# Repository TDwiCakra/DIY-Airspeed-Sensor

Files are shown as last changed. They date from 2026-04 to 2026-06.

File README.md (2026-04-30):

# Airspeed Sensor - Sistem Pengukur Kecepatan Udara





Sistem pengukur kecepatan udara berbasis prinsip Pitot Tube menggunakan dua sensor barometer BMP280, dilengkapi dengan Kalman Filter untuk pembacaan yang stabil dan akurat.

Note:
- Pastikan kedua sensor BMP280 terpasang dengan benar sebelum upload program
- Lakukan kalibrasi awal (zeroing) dengan menekan tombol saat kondisi angin tenang / tidak ada aliran udara

## 💡 Cara Kerja

Sistem ini mengukur kecepatan udara menggunakan prinsip **Pitot Tube** yang memanfaatkan perbedaan tekanan statis dan tekanan dinamis:

```
                    ┌──────────────┐
   Aliran Udara →   │   BMP280 #1  │  (Stagnation / Dynamic Pressure)
                    └──────────────┘
                          vs
                    ┌──────────────┐
   Aliran Udara →   │   BMP280 #2  │  (Static Pressure)
                    └──────────────┘
                           ↓
              Hitung ΔP = P1 - P2 - Offset
                           ↓
              v = √(2 × |ΔP| / ρ) × 3.6  [km/h]
                           ↓
              Output difilter dengan Kalman Filter
```

Kecepatan dihitung menggunakan persamaan Bernoulli, lalu diperhalus dengan **Kalman Filter** untuk meredam noise sensor.

---

## 🌟 Fitur Utama

- ✅ Pengukuran kecepatan udara real-time (km/h)
- ✅ Dual BMP280 sensor (I2C address 0x76 & 0x77)
- ✅ Kalman Filter untuk output yang stabil dan minim noise
- ✅ Kalibrasi otomatis offset tekanan saat startup (20 sampel)
- ✅ Fungsi Zeroing / Re-kalibrasi via tombol tekan
- ✅ Deadzone threshold (< 0.5 Pa = 0 km/h) untuk menghindari noise saat diam
- ✅ Offset koreksi suhu per sensor
- ✅ Output Serial Monitor lengkap (Suhu, Raw Speed, Filtered Speed)

---

## 🛠 Hardware Requirements

| Komponen | Spesifikasi | Jumlah |
|---|---|---|
| **Microcontroller** | Arduino (Uno/Nano/Mega) | 1 |
| **Pressure Sensor** | BMP280 (I2C, address 0x76) | 1 |
| **Pressure Sensor** | BMP280 (I2C, address 0x77) | 1 |
| **Push Button** | Tactile Switch / Push Button | 1 |
| **Resistor** | 10kΩ (opsional, sudah ada internal pullup) | 1 |
| **Pitot Tube** | Tabung pitot untuk mengarahkan angin | 1 |
| **Breadboard/PCB** | Untuk koneksi | 1 |
| **Kabel Jumper** | Male-Female, Male-Male | Secukupnya |

---

## 📥 Instalasi Arduino IDE

### Windows

1. **Download Arduino IDE**
   - Kunjungi [Arduino Official Website](https://www.arduino.cc/en/software)
   - Download versi terbaru (2.x.x atau 1.8.x)
   - Pilih "Windows Installer" (untuk instalasi mudah)

2. **Install Arduino IDE**
   - Jalankan file installer (.exe)
   - Ikuti wizard instalasi
   - Centang "Install USB Driver" saat instalasi
   - Klik "Finish" setelah selesai

3. **Buka Arduino IDE**
   - Jalankan Arduino IDE dari Start Menu
   - IDE siap digunakan

### macOS

1. **Download Arduino IDE**
   - Kunjungi [Arduino Official Website](https://www.arduino.cc/en/software)
   - Download versi untuk macOS

2. **Install Arduino IDE**
   - Buka file .dmg yang didownload
   - Drag aplikasi Arduino ke folder Applications
   - Buka Arduino IDE dari Applications

### Linux (Ubuntu/Debian)

```bash
# Download dan install Arduino IDE
wget https://downloads.arduino.cc/arduino-ide/arduino-ide_latest_Linux_64bit.AppImage

# Berikan permission untuk execute
chmod +x arduino-ide_latest_Linux_64bit.AppImage

# Jalankan Arduino IDE
./arduino-ide_latest_Linux_64bit.AppImage
```

Atau install via snap:

```bash
sudo snap install arduino
```

---

## 📚 Instalasi Library

Program ini hanya menggunakan library bawaan Arduino sehingga **tidak memerlukan instalasi library tambahan**!

Library yang digunakan:

| Library | Keterangan | Status |
|---|---|---|
| `Wire.h` | Komunikasi I2C | ✅ Built-in Arduino |

### Verifikasi Library Terinstall

```cpp
// Buka Arduino IDE dan coba compile sketch ini:
#include <Wire.h>

void setup() {}
void loop() {}
```

Jika tidak ada error, library sudah siap digunakan!

---

## 🔧 Konfigurasi Hardware

### Wiring Diagram

#### I2C Connection (BMP280 #1 & BMP280 #2)

```
Arduino UNO      BMP280 #1 (0x76)
--------------------------
5V / 3.3V  -----> VCC
GND        -----> GND
A4 (SDA)   -----> SDA
A5 (SCL)   -----> SCL
SDO        -----> GND   ← untuk set alamat 0x76

Arduino UNO      BMP280 #2 (0x77)
--------------------------
5V / 3.3V  -----> VCC
GND        -----> GND
A4 (SDA)   -----> SDA  (parallel dengan BMP280 #1)
A5 (SCL)   -----> SCL  (parallel dengan BMP280 #1)
SDO        -----> VCC  ← untuk set alamat 0x77
```

**⚠️ Penting:** Pin `SDO` pada BMP280 digunakan untuk mengatur alamat I2C:
- `SDO → GND` = alamat **0x76**
- `SDO → VCC` = alamat **0x77**

#### Tombol Zeroing

```
Arduino UNO      Button
--------------------------
D2         -----> PIN 1
GND        -----> PIN 2
```

> Internal Pull-Up diaktifkan via `INPUT_PULLUP`, sehingga tidak diperlukan resistor eksternal.

### Tips Pemasangan

1. **Sensor BMP280 #1 (Dynamic / Stagnation)**
   - Pasang menghadap aliran udara (sisi lubang pitot tube)
   - Pastikan lubang inlet tidak tertutup

2. **Sensor BMP280 #2 (Static Pressure)**
   - Pasang pada sisi yang tidak terkena aliran langsung
   - Jauhkan dari turbulensi yang tidak diinginkan

3. **Tombol Zeroing**
   - Tempatkan di posisi yang mudah dijangkau
   - Tekan saat sistem tidak ada aliran udara untuk kalibrasi ulang

---

## 📤 Upload Program ke Arduino

### 1. Persiapan

1. **Buka File Program**
   - Download file `Airspeed_Sensor.ino`
   - Buka dengan Arduino IDE: `File → Open`

2. **Sesuaikan Offset Suhu (Opsional)**

   Edit bagian ini di dalam `void loop()` jika sensor menunjukkan suhu yang tidak akurat:
   ```cpp
   float t1 = readTemperature(0x76, cal1, -1.5);   // Offset sensor #1 (-1.5°C)
   readTemperature(0x77, cal2, -8.89);              // Offset sensor #2 (-8.89°C)
   ```
   Sesuaikan nilai offset dengan mengukur selisih suhu aktual terhadap referensi termometer.

### 2. Konfigurasi Board

1. **Pilih Board**
   - `Tools → Board → Arduino AVR Boards → Arduino Uno` (sesuaikan dengan board Anda)

2. **Pilih Port COM**
   - Hubungkan Arduino ke komputer via USB
   - `Tools → Port → COMx` (Windows) atau `/dev/ttyUSBx` (Linux) atau `/dev/cu.usbmodem-xxx` (macOS)

3. **Konfigurasi Upload Settings (Arduino Uno)**
   ```
   Tools → Board: Arduino Uno
   Tools → Processor: ATmega328P
   Tools → Upload Speed: 115200
   ```

### 3. Compile & Upload

1. **Verify/Compile**
   - Klik tombol ✓ (Verify) atau `Sketch → Verify/Compile`
   - Tunggu hingga proses compile selesai
   - Pastikan tidak ada error

2. **Upload ke Arduino**
   - Klik tombol → (Upload) atau `Sketch → Upload`
   - Tunggu proses upload selesai

3. **Buka Serial Monitor**
   - `Tools → Serial Monitor`
   - Set baud rate ke **9600**
   - Tunggu pesan `"System Ready. Press Button to Toggle ON/OFF."`

---

## 🚀 Penggunaan

### Startup & Kalibrasi Awal

Saat pertama dinyalakan, sistem akan otomatis melakukan kalibrasi:

```
Calibrating... Please wait.
System Ready. Press Button to Toggle ON/OFF.
```

Kalibrasi dilakukan dengan mengambil **20 sampel** selisih tekanan antara kedua sensor dan menghitung rata-rata sebagai `pressure_offset`. Proses ini memakan waktu sekitar **1 detik**.

> ⚠️ **Pastikan tidak ada aliran udara saat proses kalibrasi startup berlangsung!**

### Membaca Output Serial

Setelah sistem ready, output akan tampil setiap 50ms:

```
Temp:25.30 Raw_V:12.45 Filtered_V:11.87
Temp:25.31 Raw_V:12.60 Filtered_V:12.10
Temp:25.30 Raw_V:0.00  Filtered_V:8.32
```

| Field | Keterangan | Satuan |
|---|---|---|
| `Temp` | Suhu dari BMP280 #1 (sudah terkoreksi offset) | °C |
| `Raw_V` | Kecepatan mentah sebelum filtering | km/h |
| `Filtered_V` | Kecepatan setelah Kalman Filter | km/h |

### Zeroing / Re-kalibrasi

Tekan tombol di **Pin D2** kapan saja untuk melakukan re-kalibrasi:

```
Zeroing / Recalibrating...
New Offset: 0.35
```

Sistem akan mengambil **10 sampel** baru dan memperbarui `pressure_offset`. Estimasi Kalman Filter juga di-reset ke 0 untuk menghindari lonjakan nilai.

---

## 🔬 Penjelasan Algoritma

### 1. Pembacaan BMP280 via I2C (Raw Driver)

Program ini **tidak menggunakan library BMP280 eksternal**, melainkan berkomunikasi langsung dengan register sensor via I2C. Hal ini membuat program lebih ringan dan tidak bergantung library tambahan.

Urutan pembacaan:
1. Baca 24 byte data kalibrasi dari register `0x88`
2. Inisialisasi sensor ke mode normal (`0xF4 = 0x27`)
3. Baca raw ADC suhu dari register `0xFA` → konversi ke °C menggunakan formula kompensasi BMP280
4. Baca raw ADC tekanan dari register `0xF7` → konversi ke Pa menggunakan `t_fine` dari kalkulasi suhu

### 2. Kalman Filter

Kalman Filter digunakan untuk meredam noise pada pembacaan kecepatan:

```
Parameters:
  error_estimate  = 2     (uncertainty awal estimasi)
  error_measure   = 0.5   (uncertainty pengukuran sensor)
  q               = 0.01  (process noise)
```

Semakin kecil nilai `error_measure`, semakin percaya sistem terhadap sensor. Semakin kecil `q`, semakin halus output namun semakin lambat respons terhadap perubahan cepat.

### 3. Perhitungan Kecepatan (Bernoulli)

```
ΔP = P1 - P2 - pressure_offset
v  = √(2 × |ΔP| / ρ) × 3.6    [km/h]

dimana:
  ρ = 1.225 kg/m³  (densitas udara standar pada 15°C, sea level)
```

Jika `|ΔP| < 0.5 Pa`, kecepatan dianggap **0** untuk menghindari noise saat tidak ada aliran udara.

---

## 📌 Pin Configuration

| Pin Arduino | Fungsi | Keterangan |
|---|---|---|
| **A4 (SDA)** | I2C Data | Terhubung ke SDA kedua BMP280 |
| **A5 (SCL)** | I2C Clock | Terhubung ke SCL kedua BMP280 |
| **D2** | Tombol Zeroing | Input dengan `INPUT_PULLUP` |

---

## 🔴 Troubleshooting

### Problem: Serial Monitor tidak menampilkan output

**Solution:**
- Pastikan baud rate di Serial Monitor diset ke **9600**
- Cek koneksi USB ke Arduino
- Coba tekan tombol Reset pada board Arduino

### Problem: Kecepatan selalu 0 padahal ada aliran udara

**Solution:**
```
1. Cek sambungan I2C (SDA/SCL) ke kedua sensor BMP280
2. Pastikan alamat I2C sensor benar (cek pin SDO)
3. Lakukan scan I2C untuk verifikasi sensor terdeteksi
4. Pastikan pressure_offset tidak terlalu besar akibat kalibrasi yang salah
5. Tekan tombol zeroing untuk kalibrasi ulang
```

Kode scan I2C untuk diagnosa:
```cpp
#include <Wire.h>
void setup() {
  Wire.begin();
  Serial.begin(9600);
  for (byte a = 1; a < 127; a++) {
    Wire.beginTransmission(a);
    if (Wire.endTransmission() == 0) {
      Serial.print("Sensor ditemukan di alamat 0x");
      Serial.println(a, HEX);
    }
  }
}
void loop() {}
```

### Problem: Nilai kecepatan sangat noise / tidak stabil

**Solution:**
- Pastikan supply daya stabil (gunakan USB yang bagus atau power supply terpisah)
- Periksa sambungan kabel I2C (gunakan kabel pendek, max 30cm)
- Tambahkan kapasitor 100nF dekat pin VCC sensor BMP280
- Turunkan nilai `error_measure` pada Kalman Filter untuk filtering lebih halus:
  ```cpp
  float error_measure = 0.2; // default 0.5, lebih kecil = lebih halus
  ```

### Problem: Kecepatan bernilai negatif atau sangat besar

**Solution:**
- Lakukan **zeroing** ulang dengan menekan tombol saat tidak ada aliran udara
- Cek apakah pemasangan fisik sensor sudah benar (sensor mana yang menghadap aliran)
- Pastikan kedua sensor tidak saling bertukar posisi (0x76 = dynamic, 0x77 = static)

### Problem: "while (!Serial)" — Arduino tidak mulai-mulai

**Catatan:** Baris `while (!Serial);` menyebabkan program menunggu Serial Monitor dibuka. Jika digunakan **tanpa komputer** (standalone), hapus baris tersebut:

```cpp
void setup() {
  Wire.begin();
  Serial.begin(9600);
  // while (!Serial);  // ← hapus / comment baris ini untuk standalone
  ...
}
```

---

## 🙏 Acknowledgments

- **Bosch Sensortec** - untuk sensor BMP280 yang andal dan terdokumentasi dengan baik
- **Arduino Community** - untuk support dan resources
- **Kalman Filter Reference** - implementasi berdasarkan prinsip Kalman Filter 1D

## 📝 Changelog

### [1.0.0] - 2026-03-04
#### Initial Release
- Dual BMP280 airspeed measurement via Pitot Tube principle
- Kalman Filter untuk output yang stabil
- Auto-kalibrasi offset tekanan saat startup
- Fungsi zeroing via push button
- Offset koreksi suhu per sensor
- Output Serial: Suhu, Raw Speed, Filtered Speed

---

## ⚠️ Disclaimer

**Sistem ini adalah alat pengukur kecepatan udara untuk keperluan eksperimen dan edukasi.**

- Akurasi pengukuran bergantung pada kualitas pemasangan fisik pitot tube
- Densitas udara yang digunakan adalah konstanta standar (1.225 kg/m³) dan **tidak** memperhitungkan variasi ketinggian atau kelembaban
- Jangan gunakan sebagai satu-satunya referensi untuk aplikasi kritis (penerbangan, dll)
- Developer tidak bertanggung jawab atas kerusakan atau kecelakaan akibat penggunaan sistem ini

---

**Last Updated:** 2026-03-04

---

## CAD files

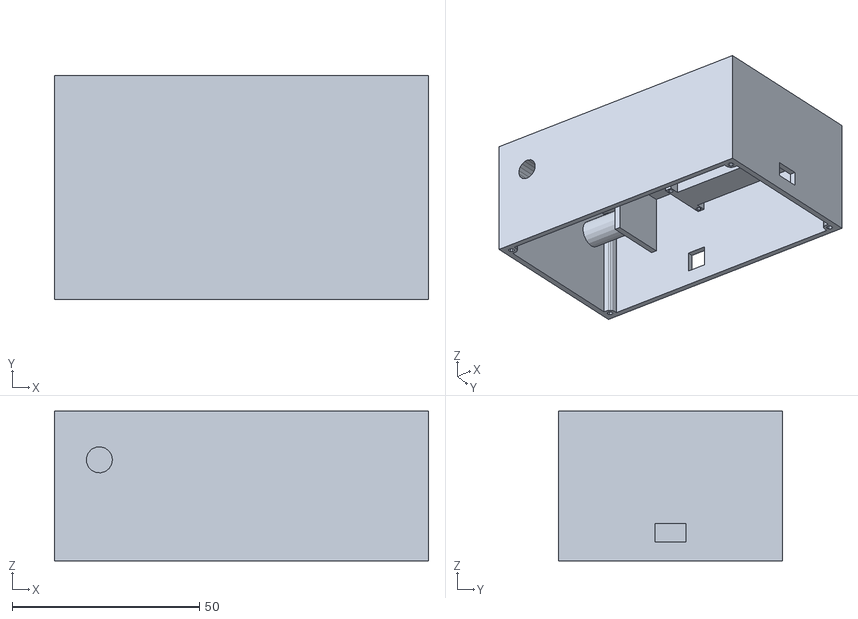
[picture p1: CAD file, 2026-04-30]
CHASIS SENSOR AIRSPEED/Part2.stl
100.0 x 60.0 x 40.0

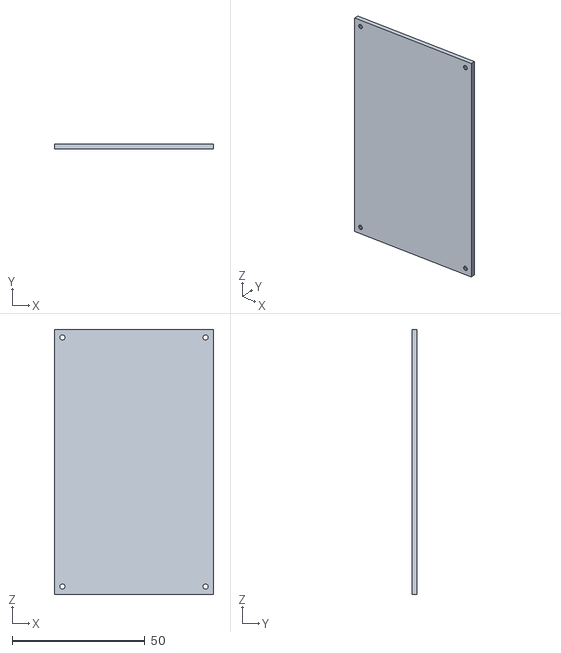
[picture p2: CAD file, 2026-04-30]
CHASIS SENSOR AIRSPEED/Part3.stl
60.0 x 2.00 x 100.0

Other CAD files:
CHASIS SENSOR AIRSPEED/OldVersions/Part2.0001.ipt
CHASIS SENSOR AIRSPEED/Part2.ipt
CHASIS SENSOR AIRSPEED/Part3.ipt

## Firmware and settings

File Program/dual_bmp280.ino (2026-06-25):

#include <Wire.h>

struct BMP280_Calib {
  uint16_t T1; 
  int16_t T2, T3;
  uint16_t P1; 
  int16_t P2, P3, P4, P5, P6, P7, P8, P9;
  int32_t t_fine;
};

struct KalmanFilter {
  float estimate       = 0;
  float error_estimate = 2;
  float error_measure  = 0.5;
  float q              = 0.001;
};

// Alamat sensor BMP280
#define ADDR_1       0x76
#define ADDR_2       0x77

// Alamat Arduino kedua sebagai I2C slave
#define SLAVE_ARDUINO_ADDR 0x08

#define BUTTON_PIN   2
#define DEADBAND_PA  10.0f
#define TEMP_OFF_1  -1.5f
#define TEMP_OFF_2  -8.89f

const float RHO_AIR = 1.225f;

BMP280_Calib cal1, cal2;
KalmanFilter kf;

float pressure_offset = 0;
bool lastButtonState  = HIGH;

// ── BMP280 ────────────────────────────────────────────────────────────────────

void readCalib(uint8_t addr, BMP280_Calib &c) {
  uint8_t d[24];

  Wire.beginTransmission(addr);
  Wire.write(0x88);
  Wire.endTransmission();

  Wire.requestFrom(addr, (uint8_t)24);

  for (int i = 0; i < 24; i++) {
    d[i] = Wire.read();
  }

  c.T1 = (d[1] << 8) | d[0];
  c.T2 = (d[3] << 8) | d[2];
  c.T3 = (d[5] << 8) | d[4];

  c.P1 = (d[7] << 8) | d[6];
  c.P2 = (d[9] << 8) | d[8];
  c.P3 = (d[11] << 8) | d[10];
  c.P4 = (d[13] << 8) | d[12];
  c.P5 = (d[15] << 8) | d[14];
  c.P6 = (d[17] << 8) | d[16];
  c.P7 = (d[19] << 8) | d[18];
  c.P8 = (d[21] << 8) | d[20];
  c.P9 = (d[23] << 8) | d[22];
}

void initSensor(uint8_t addr, BMP280_Calib &c) {
  Wire.beginTransmission(addr);
  Wire.write(0xF4);
  Wire.write(0x27);
  Wire.endTransmission();

  readCalib(addr, c);
}

float readTemperature(uint8_t addr, BMP280_Calib &c, float offset) {
  Wire.beginTransmission(addr);
  Wire.write(0xFA);
  Wire.endTransmission();

  Wire.requestFrom(addr, (uint8_t)3);

  int32_t adc = ((uint32_t)Wire.read() << 12) |
                ((uint32_t)Wire.read() << 4)  |
                ((uint32_t)Wire.read() >> 4);

  int32_t v1 = ((((adc >> 3) - ((int32_t)c.T1 << 1))) * ((int32_t)c.T2)) >> 11;

  int32_t v2 = (((((adc >> 4) - ((int32_t)c.T1)) *
                  ((adc >> 4) - ((int32_t)c.T1))) >> 12) *
                  ((int32_t)c.T3)) >> 14;

  c.t_fine = v1 + v2;

  return (float)((c.t_fine * 5 + 128) >> 8) / 100.0f + offset;
}

float readPressure(uint8_t addr, BMP280_Calib &c) {
  Wire.beginTransmission(addr);
  Wire.write(0xF7);
  Wire.endTransmission();

  Wire.requestFrom(addr, (uint8_t)3);

  int32_t adc = ((uint32_t)Wire.read() << 12) |
                ((uint32_t)Wire.read() << 4)  |
                ((uint32_t)Wire.read() >> 4);

  int64_t v1 = (int64_t)c.t_fine - 128000;
  int64_t v2 = v1 * v1 * (int64_t)c.P6;

  v2 = v2 + ((v1 * (int64_t)c.P5) << 17);
  v2 = v2 + ((int64_t)c.P4 << 35);

  v1 = ((v1 * v1 * (int64_t)c.P3) >> 8) +
       ((v1 * (int64_t)c.P2) << 12);

  v1 = (((((int64_t)1) << 47) + v1)) *
       ((int64_t)c.P1) >> 33;

  if (v1 == 0) return 0;

  int64_t p = 1048576 - adc;

  p = (((p << 31) - v2) * 3125) / v1;

  v1 = ((int64_t)c.P9 * (p >> 13) * (p >> 13)) >> 25;
  v2 = ((int64_t)c.P8 * p) >> 19;

  return (float)(((p + v1 + v2) >> 8) +
                 ((int64_t)c.P7 << 4)) / 256.0f;
}

// ── Kalman filter ─────────────────────────────────────────────────────────────

float updateKalman(KalmanFilter &kf, float z) {
  kf.error_estimate += kf.q;

  float K = kf.error_estimate /
            (kf.error_estimate + kf.error_measure);

  kf.estimate += K * (z - kf.estimate);
  kf.error_estimate = (1.0f - K) * kf.error_estimate;

  return kf.estimate;
}

// ── Zeroing ───────────────────────────────────────────────────────────────────

void calibrateOffset(int samples, int interval_ms) {
  float sum = 0;

  for (int i = 0; i < samples; i++) {
    readTemperature(ADDR_1, cal1, 0);
    readTemperature(ADDR_2, cal2, 0);

    float p1 = readPressure(ADDR_1, cal1);
    float p2 = readPressure(ADDR_2, cal2);

    sum += p1 - p2;

    delay(interval_ms);
  }

  pressure_offset = sum / samples;
  kf.estimate = 0;
}

// ── Bernoulli ─────────────────────────────────────────────────────────────────

float calcSpeed(float p1, float p2) {
  float dP = (p1 - p2) - pressure_offset;

  if (abs(dP) < DEADBAND_PA) {
    return 0.0f;
  }

  return sqrt(2.0f * abs(dP) / RHO_AIR);
}

// ── Cek chip ID BMP280 ────────────────────────────────────────────────────────

bool checkSensor(uint8_t addr) {
  Wire.beginTransmission(addr);
  Wire.write(0xD0);
  Wire.endTransmission();

  Wire.requestFrom(addr, (uint8_t)1);

  uint8_t id = Wire.read();

  return (id == 0x58 || id == 0x60);
}

// ── Kirim data ke Arduino kedua via I2C ───────────────────────────────────────

void sendDataToSlave(float dP, float raw_v, float filtered_v) {
  Wire.beginTransmission(SLAVE_ARDUINO_ADDR);

  Wire.write((byte*)&dP, sizeof(dP));
  Wire.write((byte*)&raw_v, sizeof(raw_v));
  Wire.write((byte*)&filtered_v, sizeof(filtered_v));

  Wire.endTransmission();
}

// ── Setup ─────────────────────────────────────────────────────────────────────

void setup() {
  Serial.begin(9600);
  Wire.begin();

  pinMode(BUTTON_PIN, INPUT_PULLUP);

  Serial.print(F("Sensor 0x76 (total):  "));
  if (checkSensor(ADDR_1)) {
    Serial.println(F("OK"));
    initSensor(ADDR_1, cal1);
  } else {
    Serial.println(F("TIDAK TERDETEKSI - cek wiring!"));
  }

  Serial.print(F("Sensor 0x77 (static): "));
  if (checkSensor(ADDR_2)) {
    Serial.println(F("OK"));
    initSensor(ADDR_2, cal2);
  } else {
    Serial.println(F("TIDAK TERDETEKSI - cek wiring!"));
  }

  Serial.println(F("Calibrating..."));
  calibrateOffset(20, 50);

  Serial.print(F("Offset: "));
  Serial.println(pressure_offset, 3);

  Serial.println(F("Ready. Tekan tombol untuk zeroing ulang."));
  Serial.println();

  Serial.println(F("dP(Pa)\tRaw_V(m/s)\tFiltered_V(m/s)"));
}

// ── Loop ──────────────────────────────────────────────────────────────────────

void loop() {
  bool btn = digitalRead(BUTTON_PIN);

  if (btn == LOW && lastButtonState == HIGH) {
    Serial.println(F("Zeroing..."));

    calibrateOffset(10, 20);

    Serial.print(F("New offset: "));
    Serial.println(pressure_offset, 3);

    delay(200);
  }

  lastButtonState = btn;

  readTemperature(ADDR_1, cal1, TEMP_OFF_1);
  float p1 = readPressure(ADDR_1, cal1);

  readTemperature(ADDR_2, cal2, TEMP_OFF_2);
  float p2 = readPressure(ADDR_2, cal2);

  float dP         = (p1 - p2) - pressure_offset;
  float raw_v      = calcSpeed(p1, p2);
  float filtered_v = updateKalman(kf, raw_v);

  // Kirim data ke Arduino kedua
  sendDataToSlave(dP, raw_v, filtered_v);

  Serial.print(dP, 2);
  Serial.print(F("\t"));

  Serial.print(raw_v, 2);
  Serial.print(F("\t\t"));

  Serial.println(filtered_v, 2);

  delay(50);
}

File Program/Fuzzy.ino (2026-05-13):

#include <Wire.h>

// ============================================================
// Struktur kalibrasi BMP280
// ============================================================
struct BMP280_Calib {
  uint16_t T1; int16_t T2, T3;
  uint16_t P1; int16_t P2, P3, P4, P5, P6, P7, P8, P9;
  int32_t t_fine;
};

// ============================================================
// Kalman Filter — diterapkan terpisah per sensor (sesuai jurnal)
// ============================================================
struct KalmanFilter {
  float estimate;
  float error_estimate = 2.0;
  float error_measure  = 0.5;
  float q              = 0.01;
};

BMP280_Calib cal_pt;   // Sensor 1 (0x76) — Total Pressure
BMP280_Calib cal_ps;   // Sensor 2 (0x77) — Static Pressure + Suhu

KalmanFilter kf_pt;    // Kalman untuk total pressure (Sensor 1)
KalmanFilter kf_ps;    // Kalman untuk static pressure (Sensor 2)

// ============================================================
// Konstanta fisika — Persamaan (3) & (4) jurnal Chen et al. 2024
// ============================================================
const float R_GAS  = 8.314;
const float Ma_AIR = 0.028964;
const float Mv_H2O = 0.018016;
const float Z_COMP = 1.0;
const float K_CAL  = 1.0;
const float xv_DRY = 0.0;

float pressure_offset = 0.0;

// ============================================================
// Fuzzy Filter — parameter membership function
//
//   delta kecil (< DELTA_LO) → noise → smoothing berat (alpha kecil)
//   delta besar (> DELTA_HI) → sinyal nyata → smoothing ringan (alpha besar)
//   di antara keduanya → transisi linear
//
//   Aturan fuzzy:
//     IF delta IS small  THEN alpha = ALPHA_SMOOTH   (dominasi nilai lama)
//     IF delta IS large  THEN alpha = ALPHA_TRACK    (dominasi nilai baru)
//   Defuzzifikasi: weighted average (centroid)
// ============================================================
const float DELTA_LO     = 0.05;  // m/s — batas bawah: dianggap noise
const float DELTA_HI     = 0.40;  // m/s — batas atas: dianggap sinyal nyata
const float ALPHA_SMOOTH = 0.10;  // alpha saat noise (halus, lambat)
const float ALPHA_TRACK  = 0.90;  // alpha saat perubahan nyata (responsif)

float v_fuzzy = 0.0;              // state output fuzzy

const int BUTTON_PIN   = 2;
bool lastButtonState   = HIGH;

// ============================================================
// Fungsi BMP280
// ============================================================
void readCalibrationData(uint8_t addr, BMP280_Calib &c) {
  uint8_t d[24];
  Wire.beginTransmission(addr);
  Wire.write(0x88);
  Wire.endTransmission();
  Wire.requestFrom(addr, (uint8_t)24);
  for (int i = 0; i < 24; i++) d[i] = Wire.read();
  c.T1 = (d[1]<<8)|d[0]; c.T2 = (d[3]<<8)|d[2]; c.T3 = (d[5]<<8)|d[4];
  c.P1 = (d[7]<<8)|d[6]; c.P2 = (d[9]<<8)|d[8]; c.P3 = (d[11]<<8)|d[10];
  c.P4 = (d[13]<<8)|d[12]; c.P5 = (d[15]<<8)|d[14]; c.P6 = (d[17]<<8)|d[16];
  c.P7 = (d[19]<<8)|d[18]; c.P8 = (d[21]<<8)|d[20]; c.P9 = (d[23]<<8)|d[22];
}

void initSensor(uint8_t addr, BMP280_Calib &c) {
  Wire.beginTransmission(addr);
  Wire.write(0xF4);
  Wire.write(0x27);
  Wire.endTransmission();
  readCalibrationData(addr, c);
}

float readTemperature(uint8_t addr, BMP280_Calib &c, float offset) {
  Wire.beginTransmission(addr);
  Wire.write(0xFA);
  Wire.endTransmission();
  Wire.requestFrom(addr, (uint8_t)3);
  int32_t adc = ((uint32_t)Wire.read()<<12)|((uint32_t)Wire.read()<<4)|((uint32_t)Wire.read()>>4);
  int32_t v1 = ((((adc>>3) - ((int32_t)c.T1<<1))) * ((int32_t)c.T2)) >> 11;
  int32_t v2 = (((((adc>>4) - ((int32_t)c.T1)) * ((adc>>4) - ((int32_t)c.T1))) >> 12) * ((int32_t)c.T3)) >> 14;
  c.t_fine = v1 + v2;
  return (float)((c.t_fine * 5 + 128) >> 8) / 100.0 + offset;
}

float readPressure(uint8_t addr, BMP280_Calib &c) {
  Wire.beginTransmission(addr);
  Wire.write(0xF7);
  Wire.endTransmission();
  Wire.requestFrom(addr, (uint8_t)3);
  int32_t adc = ((uint32_t)Wire.read()<<12)|((uint32_t)Wire.read()<<4)|((uint32_t)Wire.read()>>4);
  int64_t v1 = (int64_t)c.t_fine - 128000;
  int64_t v2 = v1 * v1 * (int64_t)c.P6;
  v2 = v2 + ((v1 * (int64_t)c.P5) << 17);
  v2 = v2 + ((int64_t)c.P4 << 35);
  v1 = ((v1 * v1 * (int64_t)c.P3) >> 8) + ((v1 * (int64_t)c.P2) << 12);
  v1 = (((((int64_t)1) << 47) + v1)) * ((int64_t)c.P1) >> 33;
  if (v1 == 0) return 0;
  int64_t p = 1048576 - adc;
  p = (((p << 31) - v2) * 3125) / v1;
  v1 = (((int64_t)c.P9) * (p>>13) * (p>>13)) >> 25;
  v2 = (((int64_t)c.P8) * p) >> 19;
  return (float)(((p + v1 + v2) >> 8) + ((int64_t)c.P7 << 4)) / 256.0;
}

// ============================================================
// Kalman Update
// ============================================================
float updateKalman(KalmanFilter &kf, float zk) {
  kf.error_estimate += kf.q;
  float Kk = kf.error_estimate / (kf.error_estimate + kf.error_measure);
  kf.estimate += Kk * (zk - kf.estimate);
  kf.error_estimate = (1.0 - Kk) * kf.error_estimate;
  return kf.estimate;
}

// ============================================================
// Hitung airspeed — Persamaan (4) jurnal Chen et al. 2024
//   v = K · sqrt( 2·Z·R·T·|deltaP| / (Ma·(1-xv·(1-Mv/Ma))·ps) )
// ============================================================
float calculateSpeed(float pt, float ps, float T_c) {
  float deltaP = (pt - ps) - pressure_offset;
  if (abs(deltaP) < 0.5) return 0.0;
  if (ps <= 0.0) return 0.0;
  float T_K = T_c + 273.15;
  float hum = 1.0 - xv_DRY * (1.0 - Mv_H2O / Ma_AIR);
  return K_CAL * sqrt((2.0 * Z_COMP * R_GAS * T_K * abs(deltaP))
                      / (Ma_AIR * hum * ps));  // m/s
}

// ============================================================
// Fuzzy Adaptive Filter
//
//   Membership functions (trapezoid/linear):
//     mu_small(d) = max(0, 1 - d/DELTA_LO)          — noise zone
//     mu_large(d) = max(0, min(1,(d-DELTA_LO)/(DELTA_HI-DELTA_LO))) — signal zone
//
//   Rules & defuzzifikasi (weighted average / centroid):
//     alpha = (mu_small*ALPHA_SMOOTH + mu_large*ALPHA_TRACK)
//             / (mu_small + mu_large)
//
//   Output:
//     v_out = alpha*v_new + (1-alpha)*v_prev
// ============================================================
float fuzzyFilter(float v_new, float v_prev) {
  float delta = abs(v_new - v_prev);

  // Derajat keanggotaan
  float mu_small = max(0.0f, 1.0f - delta / DELTA_LO);
  float mu_large = max(0.0f, min(1.0f, (delta - DELTA_LO) / (DELTA_HI - DELTA_LO)));

  float denom = mu_small + mu_large;
  float alpha;
  if (denom < 1e-6) {
    alpha = ALPHA_SMOOTH;  // default: noise suppression
  } else {
    alpha = (mu_small * ALPHA_SMOOTH + mu_large * ALPHA_TRACK) / denom;
  }

  return alpha * v_new + (1.0 - alpha) * v_prev;
}
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

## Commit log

2026-05-21 Airspeed Sensor Kalman V2
    Refactor Kalman filter and sensor calibration logic, improve variable initialization, and enhance readability.
2026-06-25 Update Kode Pengiriman I2C
    Tambahan kode pengiriman melalui I2C ke arduino kedua
